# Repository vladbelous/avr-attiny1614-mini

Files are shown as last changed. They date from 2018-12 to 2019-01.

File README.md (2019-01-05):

# AVR Attiny1614 (tinyAVR 1-Series) mini board

This is a simple breakout board for Attiny1614 MCU with a button and some pins dedicated to switching loads via MOSFETs.

Attiny1614 ([datasheet](http://ww1.microchip.com/downloads/en/DeviceDoc/ATtiny1614-data-sheet-40001995A.pdf)) is a new 8-bit AVR part from tinyAVR 1-Series.
In many important ways its architecture is much closer to atxmega rather than to (previous) attiny/atmega parts.
In fact, in avr-gcc it is categorized under avrxmega3 architecture.

This particular board has:
* Pin PA4 connected to high-side P-MOSFET for powering/driving an external component, using same VIN supply and common GND. This pin is **active low**.
* Pin PA5  connected to low-side N-MOSFET for driving a load using a separate supply (VEXT pin). Grounds levels will be separate. This pin is **active high**.
* Footprints for optional pull-up resistors for I2C.

This board has already been fabricated and tested to work.
It is available as a [shared project on OSHPark](https://oshpark.com/shared_projects/I7XN0JuT).

### Note on UPDI/~RESET pin:
Pin PA0 (UPDI/~RESET) can be used for either programming (via UPDI protocol) or RESET source functionality, but *you have to choose* between the two via a fuse setting. By default the fuse is setup for UPDI.

If you set the fuses for RESET source, programming the chip will require applying 12V, which is somewhat inconvenient.

Some workarounds:
* Keep the fuse in UPDI mode: you can still use the pin as digital input, and hence implement reset functionality in software (e.g. via interrupt, polling, etc). This is less reliable, since it assumes your MCU is in working state.
* Use/create a bootloader (I'm not aware of any existing yet for this part) that will allow you to program the chip via UART (similar to Arduino). Then you can change the fuse to enable it as RESET source.

Overall, this presents some inconvenience in scenarios when you need a reliable RESET.
This may be important in low voltage situations -- if your MCU gets stuck in some non-working state, a physical RESET signal is needed. Some mitigation is paying more attention to BOD (brown-out detection) settings.

### Development toolchain:
See https://github.com/vladbelous/tinyAVR_gcc_setup for details on how to setup a toolchain based on avr-gcc, avrdude and jtag2updi.

## Schematic:
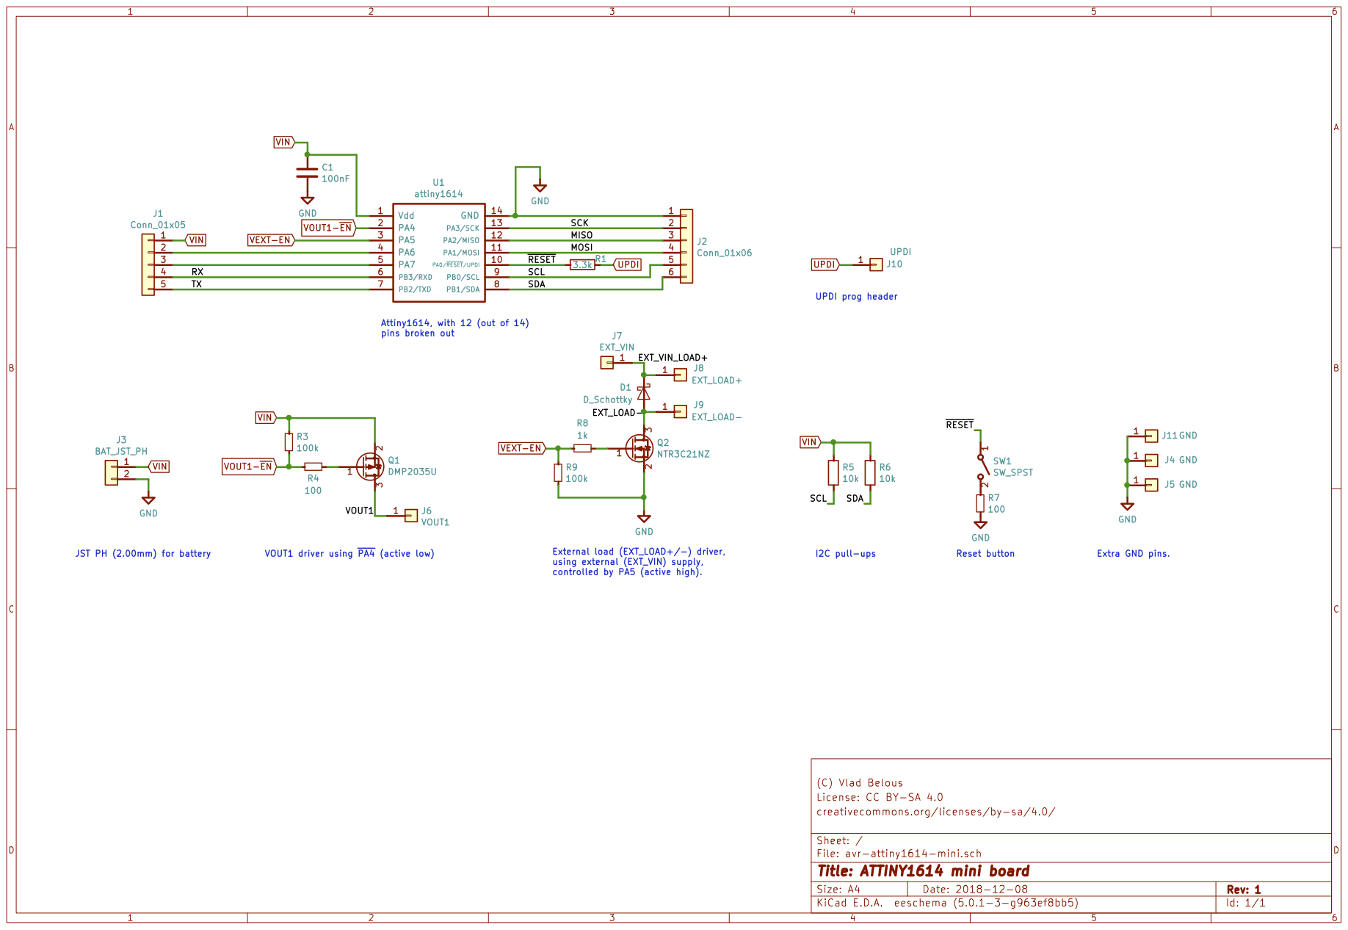
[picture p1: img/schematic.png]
schematic


## Layout (front):
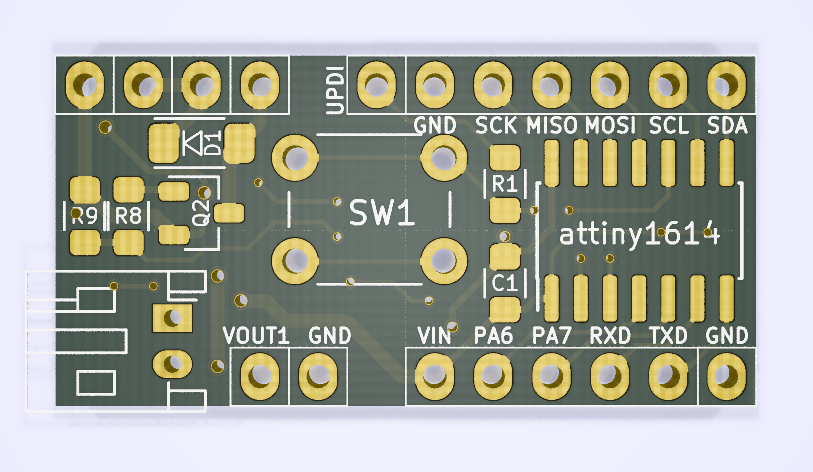
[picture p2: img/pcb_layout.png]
layout


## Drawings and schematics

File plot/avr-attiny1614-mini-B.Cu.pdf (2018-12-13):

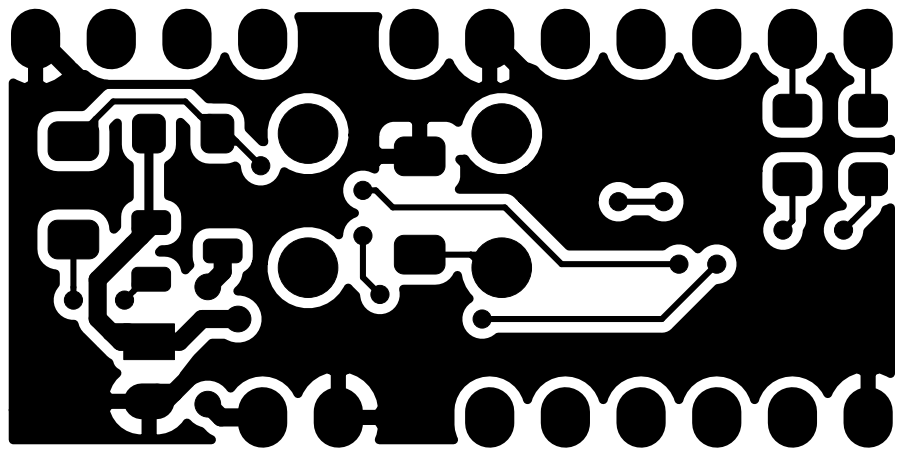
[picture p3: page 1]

(C) Vlad Belous
File: avr-attiny1614-mini.kicad_pcb Sheet: creativecommons.org/licenses/by-sa/4.0/ License: CC BY-SA 4.0

Id: 1/1 Title: ATTINY1614 mini board

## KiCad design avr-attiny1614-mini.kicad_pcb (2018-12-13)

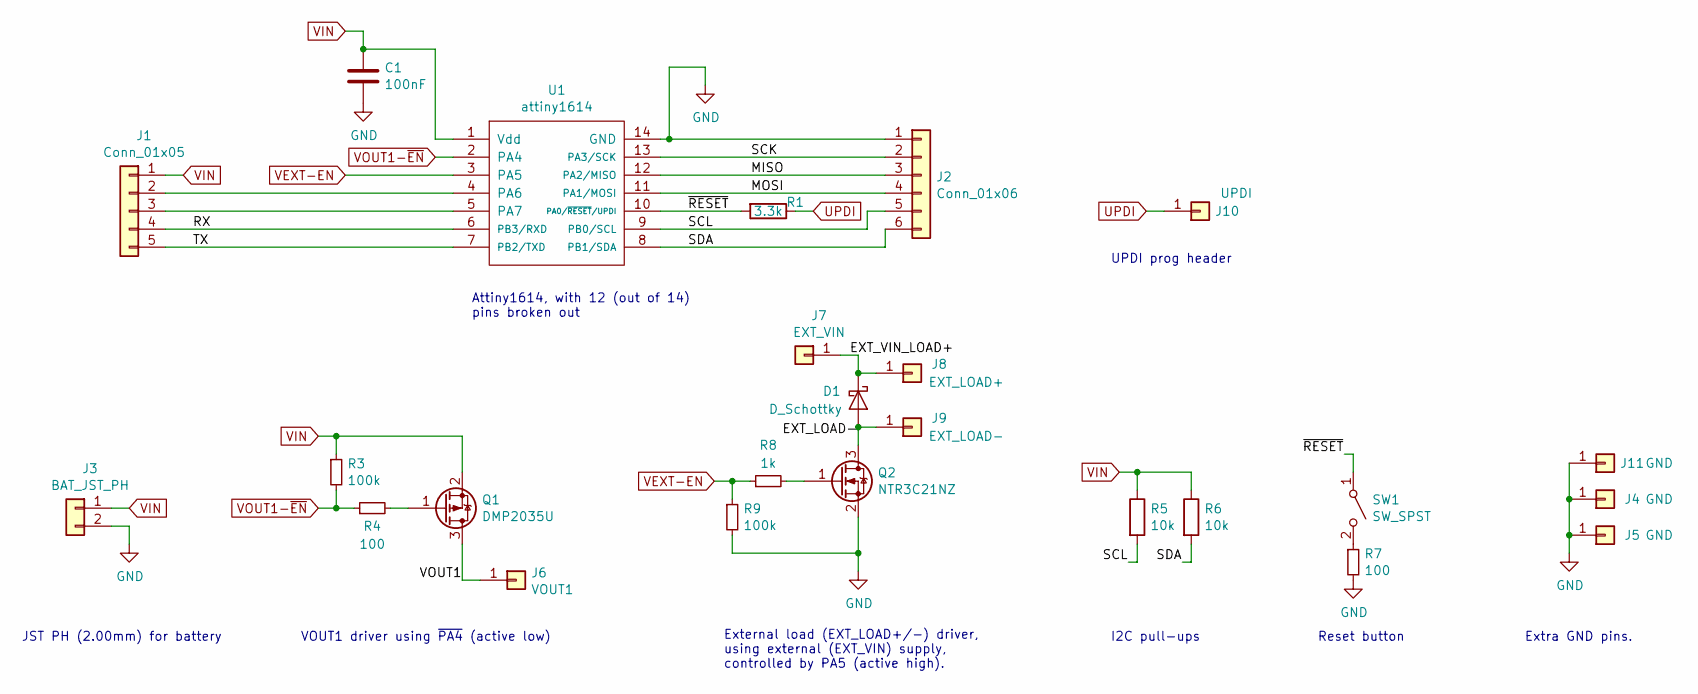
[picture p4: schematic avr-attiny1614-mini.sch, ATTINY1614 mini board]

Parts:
C1: 100nF; 0805_HS
D1: D_Schottky; 1206_Diode_HS
J1: Conn_01x05; Pin_Header_Straight_1x05_Pitch2.54mm
J2: Conn_01x06; Pin_Header_Straight_1x06_Pitch2.54mm
J3: BAT_JST_PH; JST_PH_S2B-PH-K_02x2.00mm_Angled
J4, J5, J11: GND; Pin_Header_Straight_1x01_Pitch2.54mm
J6: VOUT1; Pin_Header_Straight_1x01_Pitch2.54mm
J7: EXT_VIN; Pin_Header_Straight_1x01_Pitch2.54mm
J8: EXT_LOAD+; Pin_Header_Straight_1x01_Pitch2.54mm
J9: EXT_LOAD-; Pin_Header_Straight_1x01_Pitch2.54mm
J10: UPDI; Pin_Header_Straight_1x01_Pitch2.54mm
Q1: DMP2035U; SOT-23_HS
Q2: NTR3C21NZ; SOT-23_HS
R1: 3.3k; 0805_HS
R3, R9: 100k; 0805_HS
R4, R7: 100; 1206_HS
R5, R6: 10k; 0805_HS
R8: 1k; 0805_HS
SW1: SW_SPST; SW_PUSH_6mm
U1: attiny1614; SOIC-14_3.9x8.7mm_Pitch1.27mm_HS

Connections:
/EXT_LOAD-: D1.2 (A), J9.1, Q2.3 (D)
/EXT_VIN_LOAD+: D1.1 (K), J7.1, J8.1
/MISO: J2.3, U1.12 (PA2/MISO); also elsewhere on the board
/MOSI: J2.4, U1.11 (PA1/MOSI); also elsewhere on the board
/RX: J1.4, U1.6 (PB3/RXD); also elsewhere on the board
/SCK: J2.2, U1.13 (PA3/SCK); also elsewhere on the board
/SCL: J2.5, R5.2, U1.9 (PB0/SCL); also elsewhere on the board
/SDA: J2.6, R6.2, U1.8 (PB1/SDA); also elsewhere on the board
/TX: J1.5, U1.7 (PB2/TXD); also elsewhere on the board
/VOUT1: J6.1, Q1.3 (D)
/~RESET: R1.2, SW1.1 (A), U1.10 (PA0/~RESET~/UPDI); also elsewhere on the board
GND: C1.2, J2.1, J3.2, J4.1, J5.1, J11.1, Q2.2 (S), R7.2, R9.2, U1.14 (GND); also elsewhere on the board
unnamed 12: J1.2, U1.4 (PA6); also elsewhere on the board
unnamed 13: J1.3, U1.5 (PA7); also elsewhere on the board
unnamed: Q1.1 (G), R4.2
unnamed: Q2.1 (G), R8.2
unnamed: R7.1, SW1.2 (B)
UPDI: J10.1, R1.1
VEXT-EN: R8.1, R9.1, U1.3 (PA5); also elsewhere on the board
VIN: C1.1, J1.1, J3.1, Q1.2 (S), R3.1, R5.1, R6.1, U1.1 (Vdd); also elsewhere on the board
VOUT1-~EN: R3.2, R4.1, U1.2 (PA4); also elsewhere on the board

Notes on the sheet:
I2C pull-ups
Reset button
JST PH (2.00mm) for battery
VOUT1 driver using ~PA4~ (active low)
Attiny1614, with 12 (out of 14) pins broken out
External load (EXT_LOAD+/-) driver, using external (EXT_VIN) supply, controlled by PA5 (active high).
Extra GND pins.
UPDI prog header

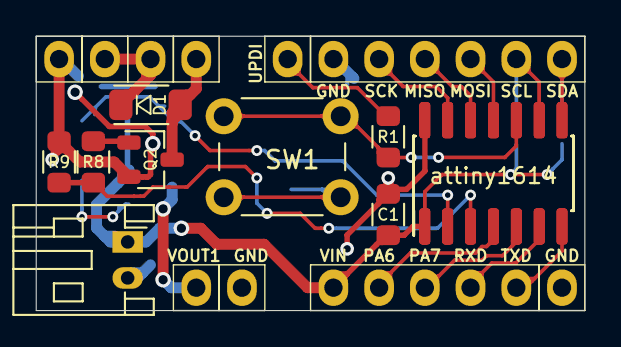
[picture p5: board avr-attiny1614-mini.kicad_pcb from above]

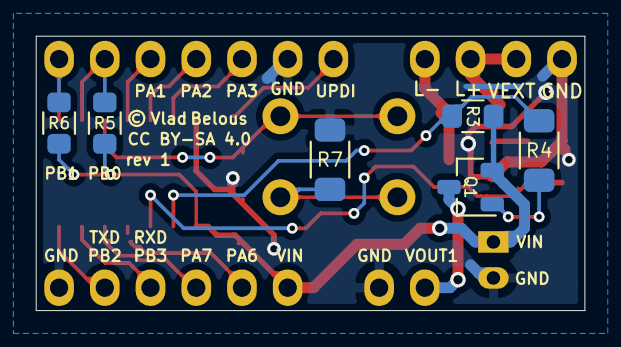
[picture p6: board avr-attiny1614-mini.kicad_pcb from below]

Board: 2 copper layers, 30.5 x 15.2 mm, 26 parts (6 on the bottom side), 21 nets.

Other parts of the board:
U1#2: attiny1614; SOIC-14_3.9x8.7mm_Pitch1.27mm_HS

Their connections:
/MISO: U1#2.12; also elsewhere on the board
/MOSI: U1#2.11; also elsewhere on the board
/RX: U1#2.6; also elsewhere on the board
/SCK: U1#2.13; also elsewhere on the board
/SCL: U1#2.9; also elsewhere on the board
/SDA: U1#2.8; also elsewhere on the board
/TX: U1#2.7; also elsewhere on the board
/~RESET: U1#2.10; also elsewhere on the board
GND: U1#2.14; also elsewhere on the board
unnamed 12: U1#2.4; also elsewhere on the board
unnamed 13: U1#2.5; also elsewhere on the board
VEXT-EN: U1#2.3; also elsewhere on the board
VIN: U1#2.1; also elsewhere on the board
VOUT1-~EN: U1#2.2; also elsewhere on the board

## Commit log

2018-12-09 Setup basic footprints
    [avr-attiny1614-mini.kicad_pcb, avr-attiny1614-mini.sch]
2018-12-09 Initial version of complete schematic
2018-12-10 Setup design rules
    [avr-attiny1614-mini.kicad_pcb]
2018-12-10 Remove VSENSE. Add EXT_LOAD driver.
    [avr-attiny1614-mini.sch]
2018-12-10 Add micro USB for power
    [avr-attiny1614-mini.sch]
2018-12-10 Remove micro USB; minor tunings
    [avr-attiny1614-mini.sch]
2018-12-11 Layout exploring
    [avr-attiny1614-mini.kicad_pcb, avr-attiny1614-mini.sch]
2018-12-12 Approx placement for 1.2in x 0.6in board.
    [avr-attiny1614-mini.kicad_pcb, avr-attiny1614-mini.sch]
2018-12-12 Routing part 1
    [avr-attiny1614-mini.kicad_pcb]
2018-12-12 Complete routing; Draft.
    [avr-attiny1614-mini.kicad_pcb]
2018-12-13 Finished 1.2in x 0.6in layout
    [avr-attiny1614-mini.kicad_pcb]
